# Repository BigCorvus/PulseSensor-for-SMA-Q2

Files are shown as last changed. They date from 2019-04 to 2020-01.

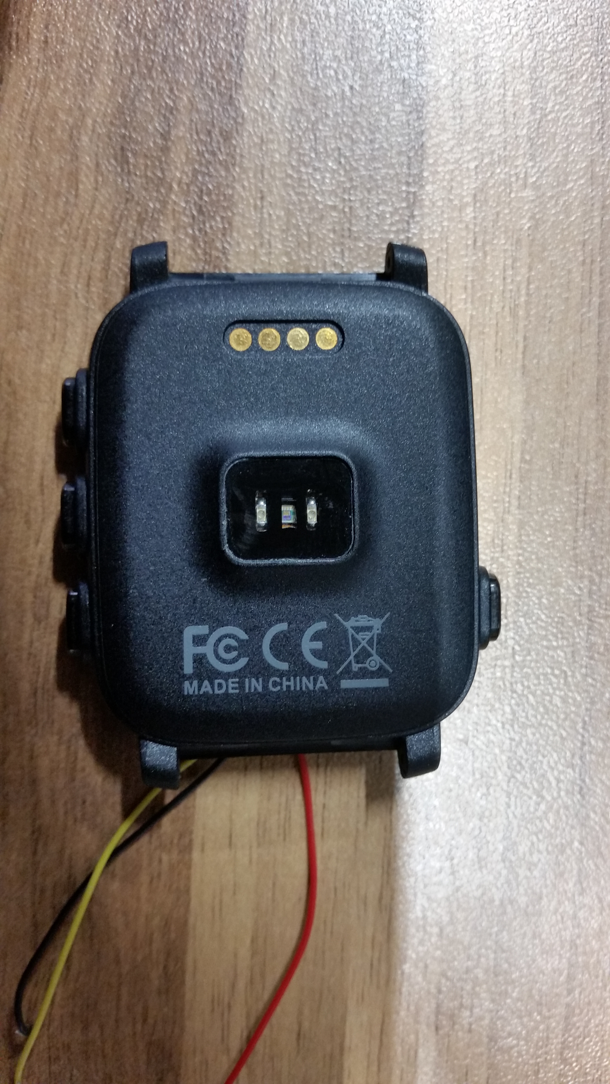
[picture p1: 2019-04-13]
20190413_134755.jpg

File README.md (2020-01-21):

# PulseSensor-for-SMA-Q2
The Pulse Sensor from https://pulsesensor.com re-designed to be made on a tiny flex PCB to replace the HR sensor of  the SMA-Q2 watch.
Have the board manufactured via the OSHpark flex sevice. This way the board remains as low profile as possible. As a light shield to avoid light hitting the ADPS-9008 from the sides I used a piece of the black component tape the SC70-5 style opamp came packaged in. Just had to cafully cut out the bottom of the tiny tray et voila! This is usable for PPG acquisition from the wrist, although the peaks are less pronounced than on the fingertips. I ended up using higher value current limiting resistors for the LEDs, something around 1.2 kohm seemed more reasonable since otherwise the sensor was overwhelmed. This also limits the overall current consumption of the sensor to about 1mA. The LED current limiting resistor value probably also depends on skin color.

Note: the board version depicted on the photos is an older revision where I placed the wire pads wrong.

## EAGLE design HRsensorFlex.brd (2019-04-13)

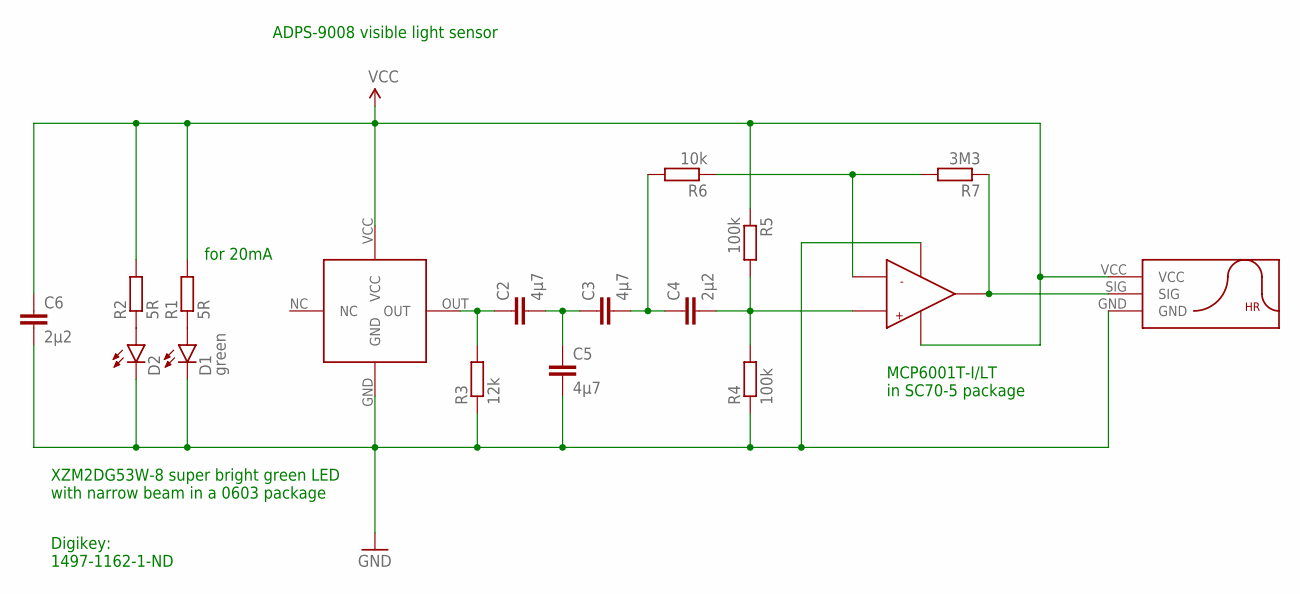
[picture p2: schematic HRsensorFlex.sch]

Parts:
C2, C3, C5: 4µ7; C0402
C4, C6: 2µ2; C0402
D1: green; LED-0603
D2: LED0603; LED-0603
R1, R2: 5R; R0402
R3: 12k; R0402
R4, R5: 100k; R0402
R6: 10k; R0402
R7: 3M3; R0402
U$1: MCP6001; SC70-5L
U$2: APDS-9008; APDS9008
U$3: HR_PADS

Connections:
GND: C5.2, C6.2, D1.C, D2.C, R3.1, R4.1, U$1.2 (VSS), U$2.GND, U$3.GND
IN+: C4.2, R4.2, R5.2, U$1.3 (+)
IN-: R6.1, R7.2, U$1.4 (-)
unnamed: D1.A, R1.1
unnamed: D2.A, R2.1
unnamed: C3.2, C4.1, R6.2
unnamed: C2.1, R3.2, U$2.OUT
unnamed: C2.2, C3.1, C5.1
OUT: R7.1, U$1.1 (OUT), U$3.SIG
VCC: C6.1, R1.2, R2.2, R5.1, U$1.5 (VDD), U$2.VCC, U$3.VCC

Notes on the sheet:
for 20mA
ADPS-9008 visible light sensor
XZM2DG53W-8 super bright green LED with narrow beam in a 0603 package
Digikey: 1497-1162-1-ND
MCP6001T-I/LT in SC70-5 package

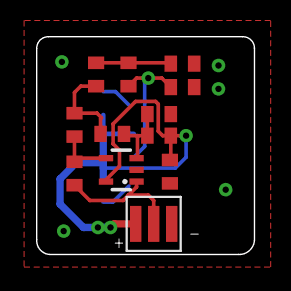
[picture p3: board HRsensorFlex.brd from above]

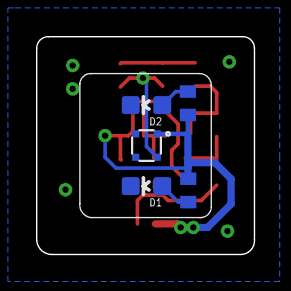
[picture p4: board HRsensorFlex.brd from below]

Board: 2 copper layers, 12.1 x 12.1 mm, 17 parts (5 on the bottom side), 10 nets.

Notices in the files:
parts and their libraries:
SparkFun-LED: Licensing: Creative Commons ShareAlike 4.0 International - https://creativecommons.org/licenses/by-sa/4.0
